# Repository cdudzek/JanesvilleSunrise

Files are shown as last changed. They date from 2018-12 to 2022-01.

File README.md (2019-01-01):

# JanesvilleSunrise
Arduino-based Sunrise Clock

## Introduction
This project is an Arduino-based clock that gradually increases the brightness on LED string lights at a preset time to emulate a sunrise, to gently wake you instead of a blaring alarm. Long Wisconsin winters are not known to have a bright sunrise every day, nor at the right time. 

## Electronics
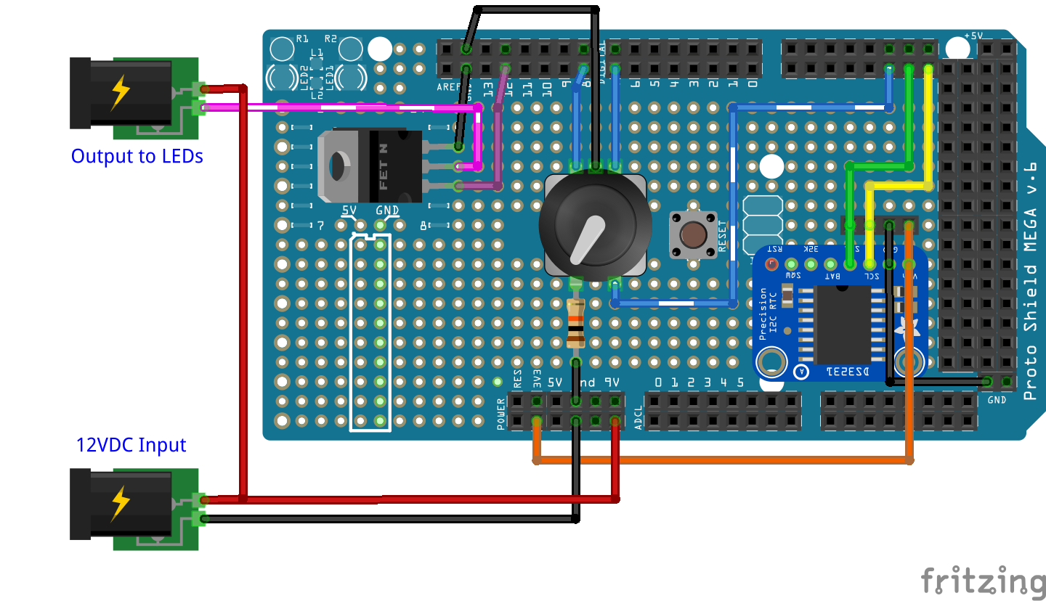
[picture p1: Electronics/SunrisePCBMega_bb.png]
Fritzing diagram
The Fritzing diagram of the electronics on the prototyping shield: 

An [Arduino Mega 2560](https://store.arduino.cc/usa/arduino-mega-2560-rev3) was used since I had one lying around, but any 5V-compatible Arduino board should work. I used a [Mega prototype shield](https://store.arduino.cc/usa/arduino-mega-proto-shield-rev3-pcb) to build the components.

A 12VDC power supply is used to power the Arduino and the LED string lights. A MOSFET is used to adjust the power to the LEDs up to 12V from a PWM pin on the Arduino board, without drawing the power through the Arduino itself. I used an [IRF530 MOSFET](https://www.vishay.com/docs/91019/91019.pdf) that I had available to power the LEDs. I had a [bright white LED tape light](https://www.amazon.com/gp/product/B00MHLIFO8/ref=oh_aui_detailpage_o05_s00?ie=UTF8&psc=1) which runs on 12VDC and included a power supply. To use RGB lights, three MOSFETs can be used to power the three LED channels separately, each driven from a separate PWM pin. 

An [Adafruit #3013 DS3231 Real Time Clock (RTC)](https://www.adafruit.com/product/3013) breakout board is used to keep accurate time, and the built-in battery backup to continue when power is lost. 

A single [Adafruit #377 Rotary Encoder](https://www.adafruit.com/product/377) is used to provide control to the user for setting the alarm time and device settings. Double-click the built-in button to enter the Setup Mode, which provides access to setting the current time, alarm time, display brightness, and maximum LED output brightness. Hold the button for a short while to start a sunrise fade-in right away. When a sunrise is happening (the LED lights are on), single-click the rotary button to cancel (or re-enable) the current sunrise cycle. 

A header is included next to the RTC to connect an [Adafruit I2C 7-Segment LED backpack](https://www.adafruit.com/product/881) as the clock display. I used the Adafruit #881 blue display, but other colors are available. The Arduino sketch and wiring could be modified to use an SPI or serial display such as the [Sparkfun #COM-11441](https://www.sparkfun.com/products/11441) display, or a [16x2 character LCD](https://www.adafruit.com/category/96), or other products. 

## Hardware and Enclosure
A simple wooden jewelry box from Hobby Lobby was used to enclose the electronics and to mount the display, encoder knob, and power jacks. 

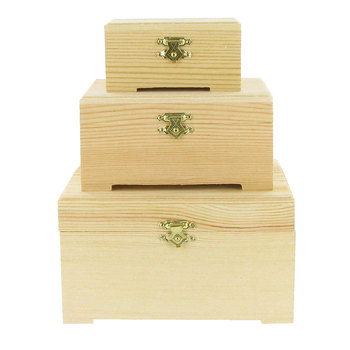
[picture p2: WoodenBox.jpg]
Wooden Box Housing, copyright Hobby Lobby


Holes were cut in the top lid for the LED display (with a simple utility knife) and the rotary knob (drill bit). Holes were drilled in the rear for the incoming 12VDC power and the output power for the LED strand. Panel mount DC barrel jacks such as the [Adafruit #610](https://www.adafruit.com/product/610) work well for mounting connectors on the wooden housing, and were the same size as the DC power supply for my LED strands. 

## Arduino Sketch
The [Arduino Sketch](https://github.com/cdudzek/JanesvilleSunrise/blob/master/MySunrise/MySunrise.ino) handles all RTC clock functions, LED clock display, user controls, and fading the LED strand lights in and out. 

The programmed alarm time is when the peak brightness for the LEDs will be on. The TIME_TO_FADE declaration in the sketch defines how long it will take to increase from darkness to full brightness. It is 20 minutes for my preferences but can be changed in the code. After the peak brightness at the exact alarm time, the lights will fade back out in an equal amount of time.

Note that the perceived brightness of the lights is not linear, see [this thread on Stack Exchange](https://electronics.stackexchange.com/questions/1983/correcting-for-non-linear-brightness-in-leds-when-using-pwm) for discussions about non-linear brightness. I implemented a simple exponential formula in the GetUserFade() function to calculate the brightness rather than hard-coding a lookup table with preset values: `fade = fmap * (fmap - 1) / 1000;`

The Arduino EEPROM is used to store user settings any time they are changed. This allows the display brightness, LED output brightness, and alarm time to be saved in case of a power failure. The RTC's own battery keeps the clock running accurately during a power outage. 

## Code Customization
Lights:
- Change `ledPin` to match the pin for your LED output voltage. Must be a PWM-capable pin on Arduinos.
- If using RGB lights, use 3 separate pins, one for each color.

Encoder:
- Change `encLow` and `encHigh` to the pins attached to your rotary encoder. They do not need to be interrupt-capable pins. 
- Change `encBtn` to one pin attached to the rotary encoder's button. This does not need to be an interrupt-capable pin. 
- Attach the rotary common/center pin to ground.
- Connect the other rotary button pin with a 10K resistor to ground (like a standard input button).
- To change the direction of the dial (CW / CCW) just reverse the encLow and encHigh values or swap the wires on the encoder itself.

Other:
- Change the address of your 7-Seg LED at `SEVENSEG_ADDR` if necessary.
- Change the `TIME_TO_FADE` to the number of seconds for the lights to fade in from completely off to completely on. Ex. 20 minutes = 20*60
- Note the Alarm Time setting is for peak brightness, not the beginning of the fade-in. Lights will fade-out for the same duration after the peak alarm time.
- Change the `AlarmOnDays` array to turn the sunrise alarm on or off for each day of the week (Sunday through Saturday). 

# NOTES
1. See the Arduino sketch for a list of required software libraries. 
1. I first attempted to use a [Teensy 3.2](https://www.pjrc.com/store/teensy32.html) microcontroller board due to its small size and great specs. However, the 3.3V board could not adequately power the LED strip lights to the full 12V. I changed over to the Arduino Mega which runs at 5V and was able to power the LEDs fully. 
1. It is possible the [Teensy 3.5](https://www.pjrc.com/store/teensy35.html) would have enough power on a 5V-tolerant board, but I have not tested it. Other Arduino boards such as the 5V-tolerant [Arduino Nano](https://store.arduino.cc/usa/arduino-nano) may also work for this project in small package. 

## Sketch Compilation
- The sketch could be successfully compiled for the Arduino Mega, Nano, Uno, and Teensy 3.5 with no code changes, with the proper supporting libraries installed. Each board would have extra available storage and memory space to add further features to the sketch.
- When compiled for an **Arduino Mega**, 8% of storage space and 14% of dynamic memory were used. 
- When compiled for an **Arduino Uno**, 63% of storage space and 58% of dynamic memory were used. 
- When compiled for an **Arduino Nano**, 67% of storage space and 58% of dynamic memory were used. 
- When compiled for a **Teensy 3.5**, 6% of storage space and 2% of dynamic memory were used. 

# License
This project is licensed under the Apache 2.0 License - see the [LICENSE](LICENSE) file for details.

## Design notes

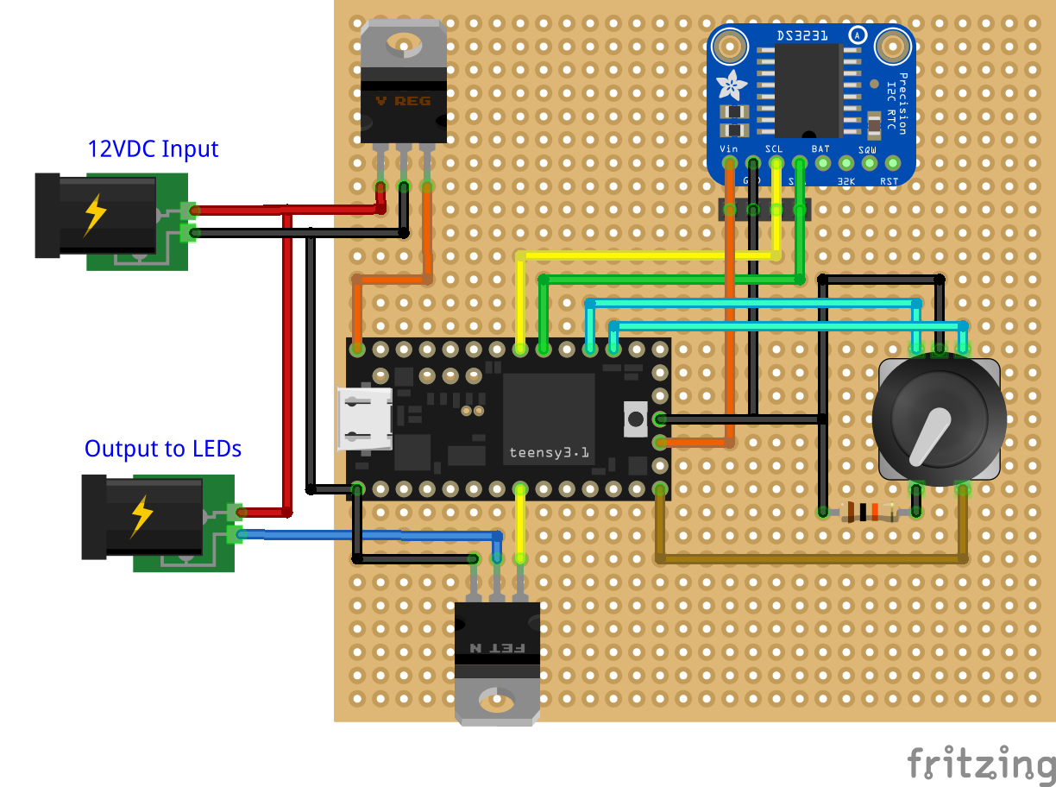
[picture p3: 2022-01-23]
Electronics/SunrisePCB-Teensy_bb.png

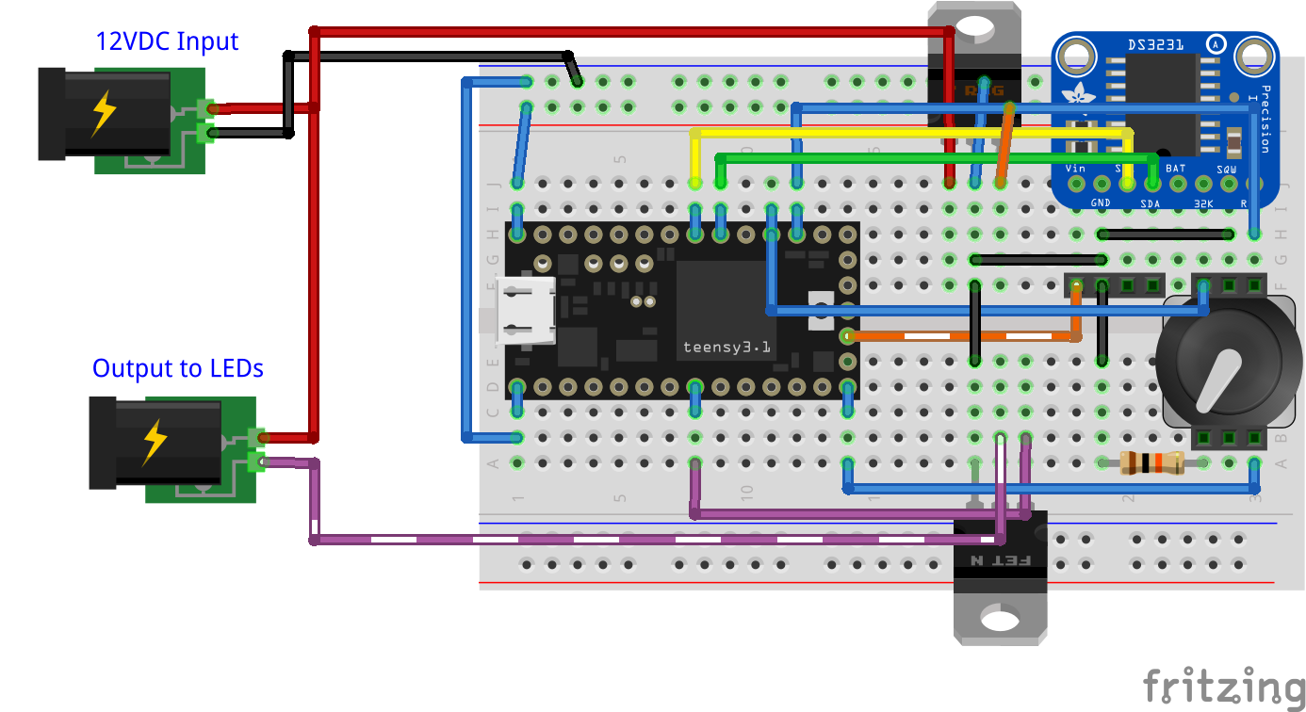
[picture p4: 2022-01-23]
Electronics/Teensy-MiniBB_bb.png

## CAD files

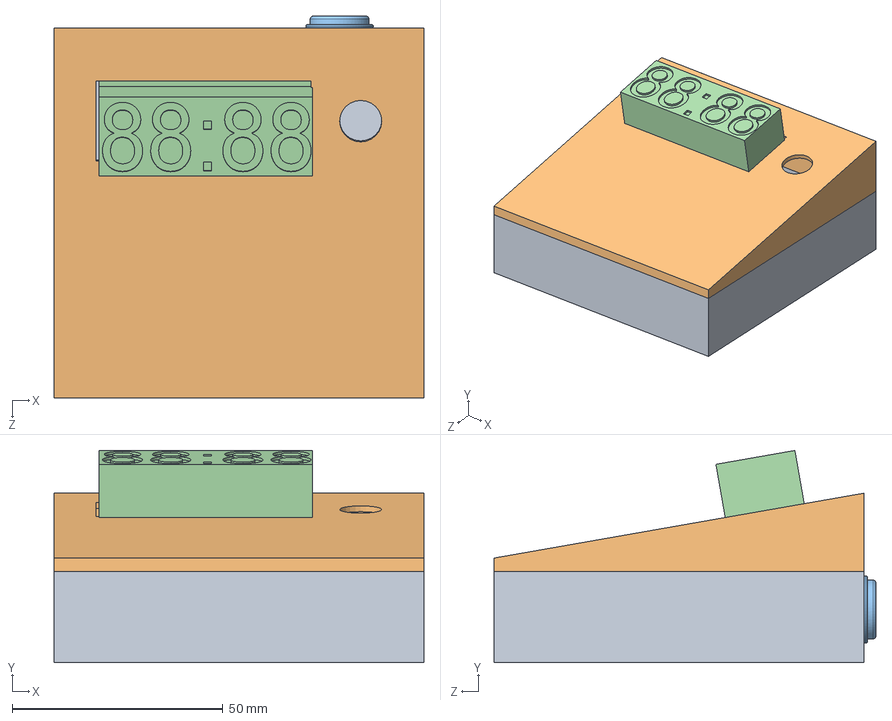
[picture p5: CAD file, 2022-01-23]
Solidworks/Assem1.SLDASM
87.8 x 50.4 x 90.7 mm
BaseBox
BoxLidSlanted
Barrel Jack
Clock

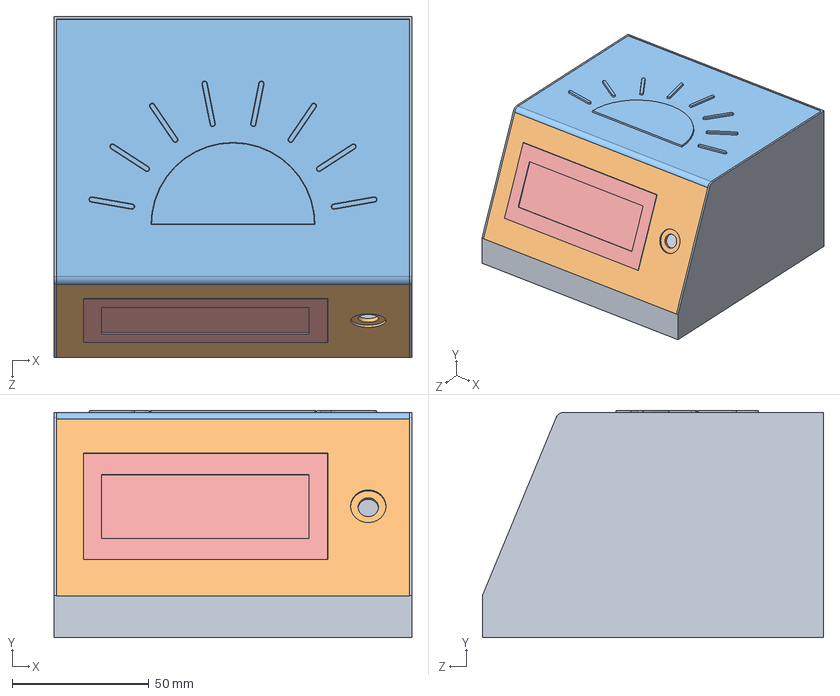
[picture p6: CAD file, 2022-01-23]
Solidworks/Box2.SLDASM
131.0 x 83.2 x 125.0 mm
Box2-Base
Box2-Front
Box2-Lid
Box2-LCDSpacer
LCD20x4

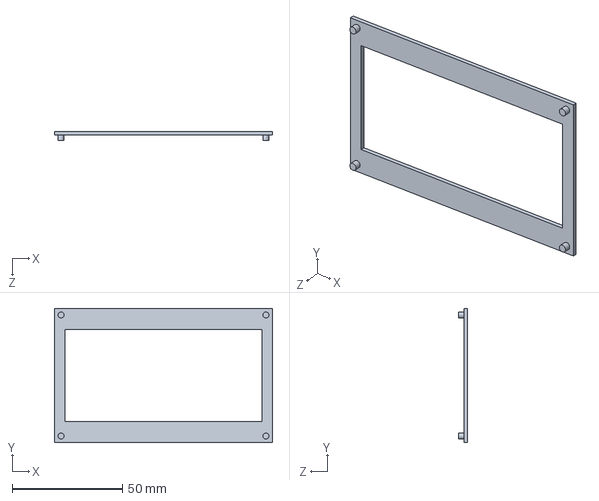
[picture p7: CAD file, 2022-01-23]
Solidworks/Box2-LCDSpacer.SLDPRT
99.0 x 61.0 x 4.00 mm

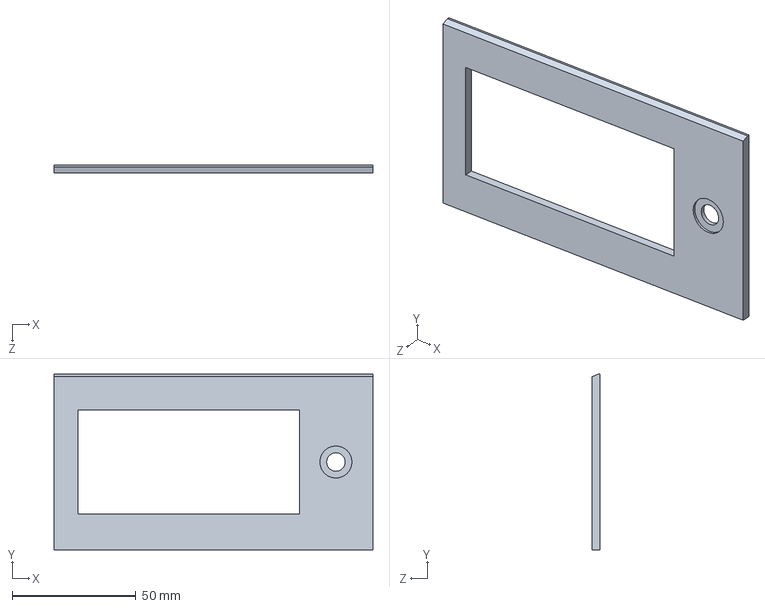
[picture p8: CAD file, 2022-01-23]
Solidworks/Box2-Front.SLDPRT
129.0 x 71.0 x 3.20 mm

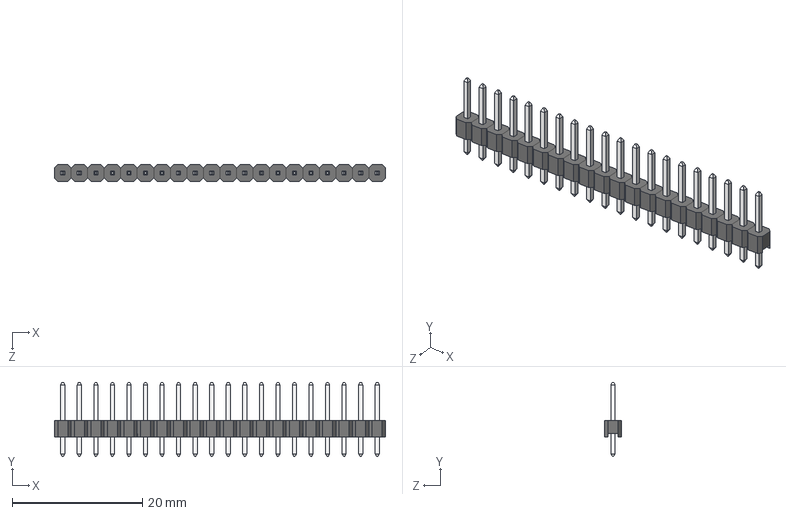
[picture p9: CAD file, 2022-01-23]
Solidworks/PREC020SAAN-RC.STEP
50.8 x 11.4 x 2.54 mm
1 row end bumps format x 20

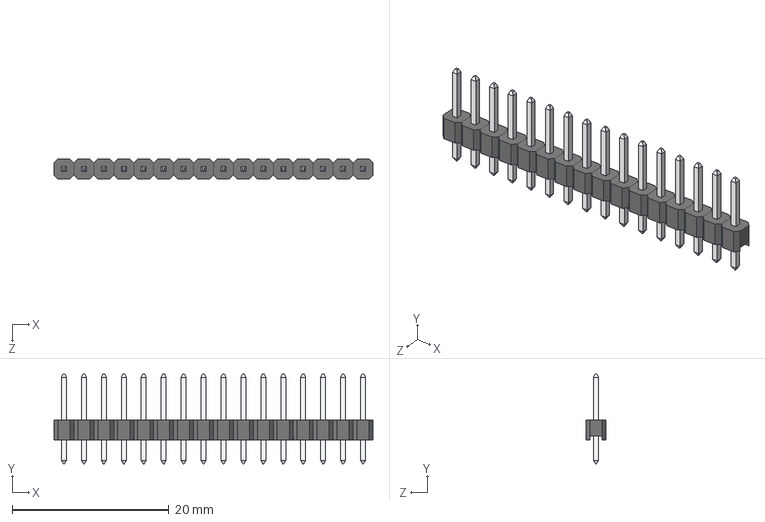
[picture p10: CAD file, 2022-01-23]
Solidworks/PREC016SAAN-RC.STEP
40.6 x 11.4 x 2.54 mm
1 row end bumps format x 16

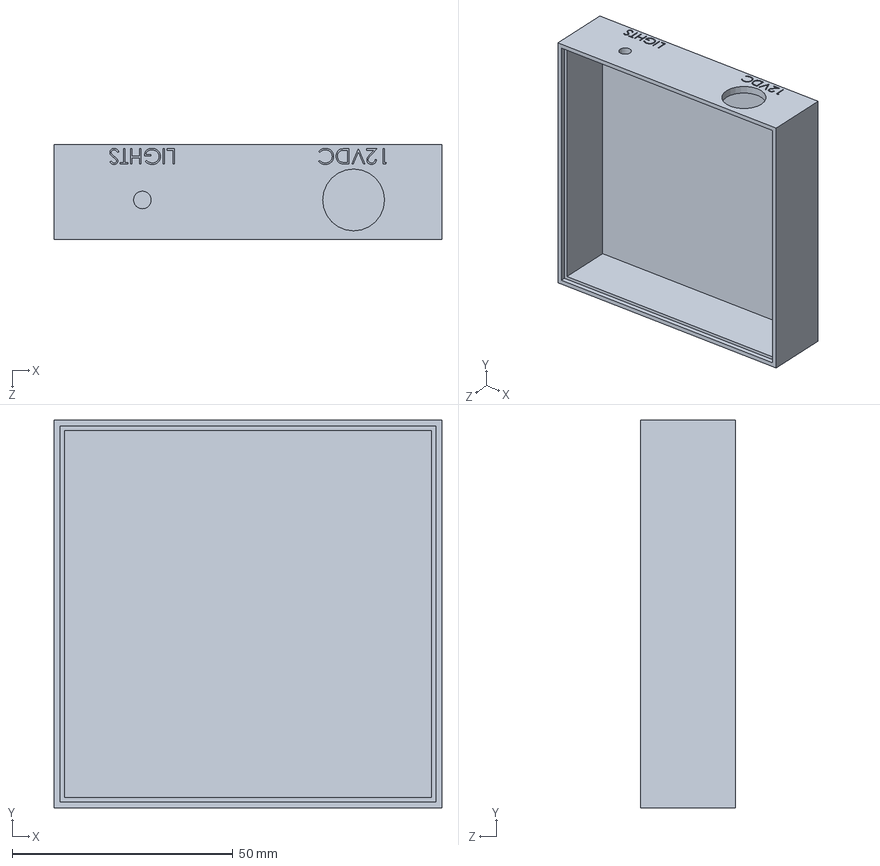
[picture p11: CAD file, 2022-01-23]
Solidworks/BaseBox.SLDPRT
87.8 x 87.8 x 21.6 mm

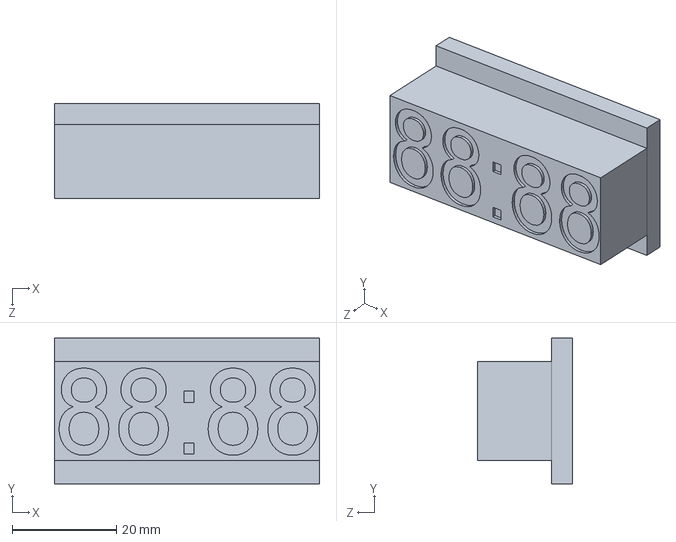
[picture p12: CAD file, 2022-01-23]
Solidworks/Clock.SLDPRT
50.8 x 27.9 x 18.3 mm

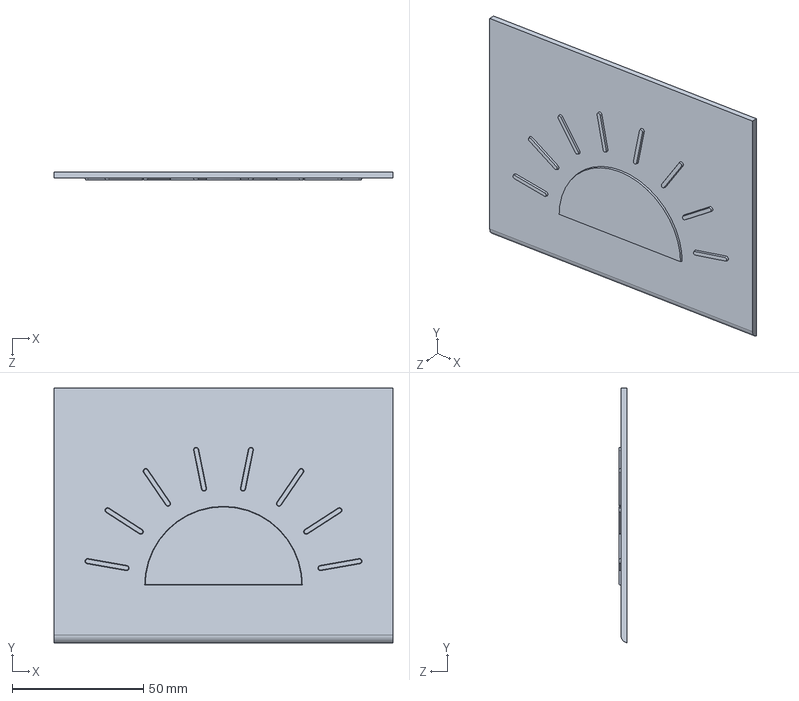
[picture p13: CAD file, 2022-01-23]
Solidworks/Box2-Lid.SLDPRT
129.0 x 97.0 x 3.20 mm

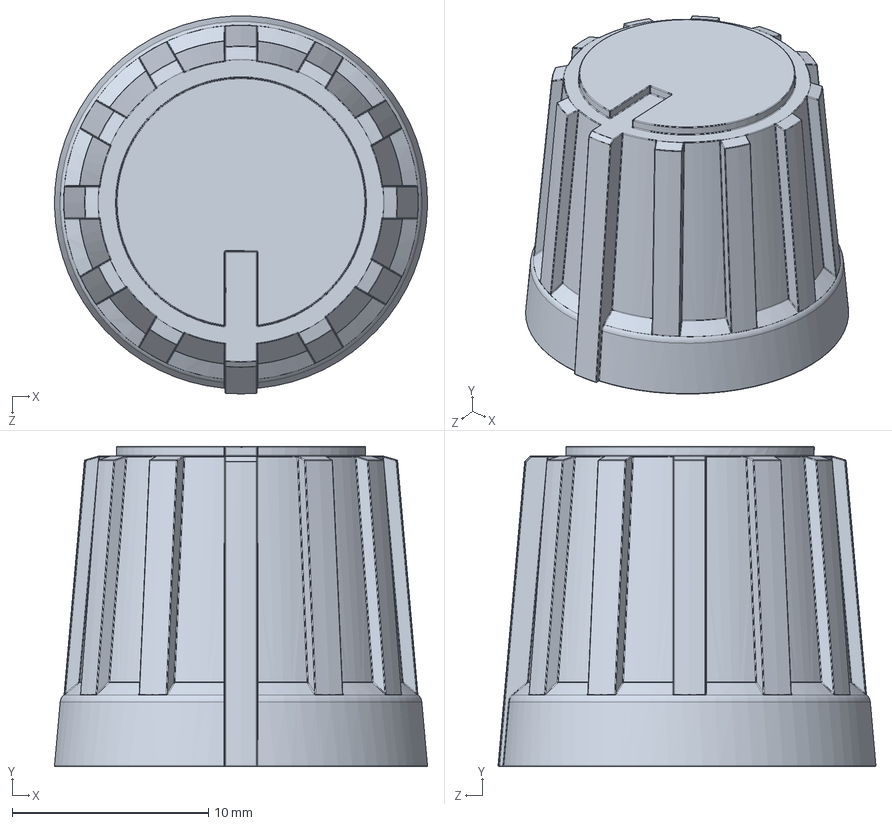
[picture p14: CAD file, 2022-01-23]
Solidworks/Turn knob.SLDPRT
19.0 x 16.3 x 19.2 mm

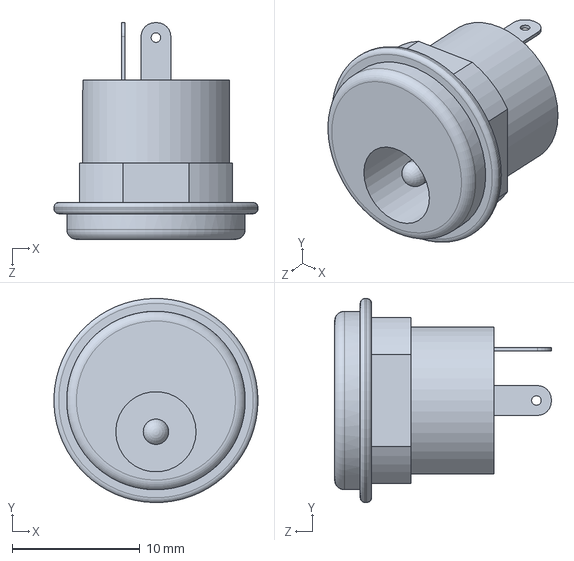
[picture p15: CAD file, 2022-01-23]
Solidworks/Barrel Jack.SLDPRT
16.0 x 16.0 x 17.0 mm

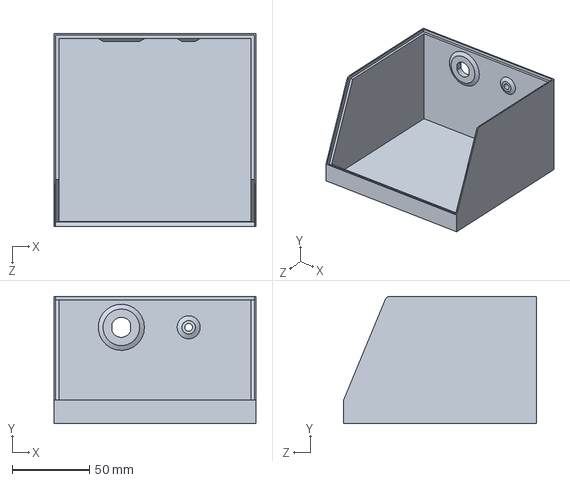
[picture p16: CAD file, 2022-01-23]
Solidworks/Box2-Base.SLDPRT
131.0 x 82.4 x 124.9 mm

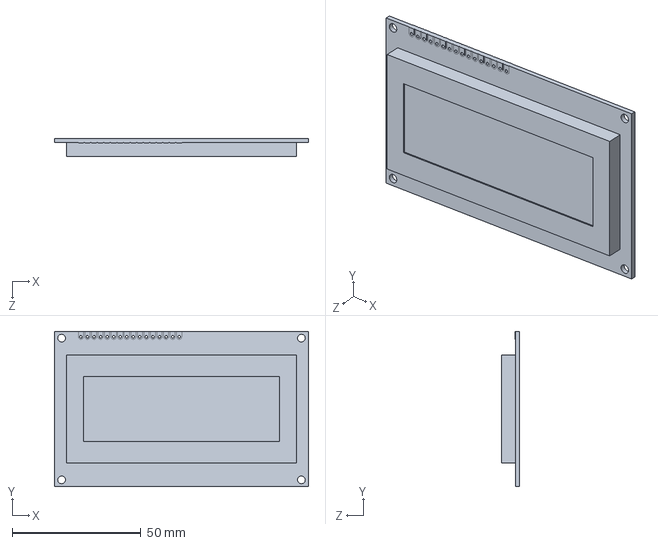
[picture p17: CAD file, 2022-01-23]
Solidworks/LCD20x4.SLDPRT
98.5 x 60.3 x 7.10 mm

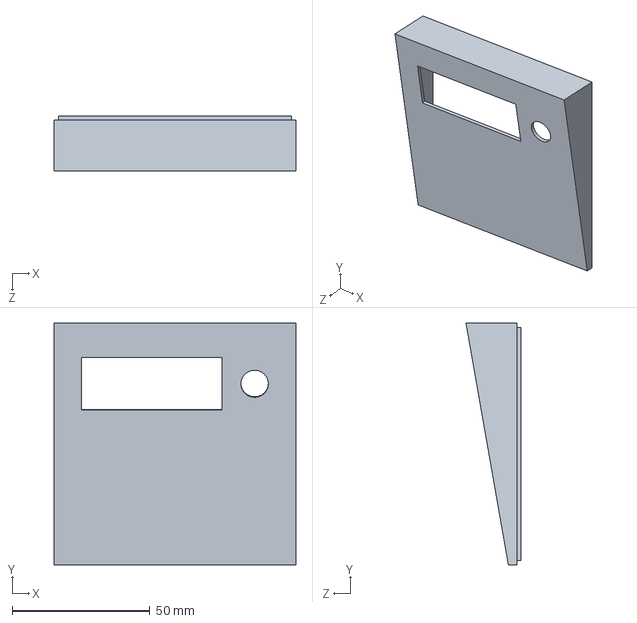
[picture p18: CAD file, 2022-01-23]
Solidworks/BoxLidSlanted.SLDPRT
87.8 x 87.8 x 20.0 mm

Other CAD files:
Solidworks/BoxLid.SLDPRT
Solidworks/Box2-Base.STL
Solidworks/Box2-Front.STL
Solidworks/Box2-LCDSpacer.STL
Solidworks/Box2-Lid.STL

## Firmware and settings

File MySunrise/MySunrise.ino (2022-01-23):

/*
 * "Janesville Sunrise"
 * December 2018 - Mr. D.
 * https://github.com/cdudzek/JanesvilleSunrise
 * 
 * Free to use, no warranty. If it breaks, not my problem.
 * See LICENSE document for Apache License 2.0
 */

/* CUSTOM BUILD TASKS:
 *   
 *  The default alarm clock is set with TimeSpan AlarmTime(...). Alarm settings will be saved to the Arduino EEPROM once changed.
 *  
 *  Change ledPin to match the pin for your LED output voltage. Must be a PWM-capable pin on Arduinos.
 *  
 *  Change encLow and encHigh to the pins attached to your rotary encoder. They do not need to be interrupt-capable pins. 
 *  Change encBtn to one pin attached to the rotary encoder's button. This does not need to be an interrupt-capable pin. 
 *  Attach the rotary common/center pin to ground.
 *  Connect the other rotary button pin with a 10K resistor to ground (like a standard input button).
 *  To change the direction of the dial (CW / CCW) just reverse the encLow and encHigh values or swap the wires on the encoder itself.
 *  
 *  Change the address of your 7-Seg LED at SEVENSEG_ADDR if necessary.
 *  
 *  Change the TIME_TO_FADE to the number of seconds for the lights to fade in from completely off to completely on. Ex. 20 minutes = 20*60
 *  Note the Alarm Time setting is for peak brightness, not the beginning of the fade-in. Lights will fade-out for the same duration after the peak alarm time.
 *  
 *  Change the AlarmOnDays array to turn the sunrise alarm on or off for each day of the week (Sunday through Saturday).
 */

/* Build information and libraries:
 *
 *  Required libraries: 
 *  Adafruit LED Backpack library: https://github.com/adafruit/Adafruit_LED_Backpack
 *  Adafruit GFX library: https://github.com/adafruit/Adafruit-GFX-Library
 *  ClickEncoder library: https://github.com/0xPIT/encoder/tree/arduino
 *  TimerOne library: http://playground.arduino.cc/Code/Timer1
 *  
 *  Products in use:
 *  Adafruit Blue 7-Segment LED with I2C backpack: https://www.adafruit.com/product/881
 *  Rotary Encoder (control knob): https://www.adafruit.com/product/377
 *  DS3231 RTC (Real-Time Clock): https://www.adafruit.com/product/3013
 *  Arduino Mega Protoshield (for circuitry): https://www.adafruit.com/product/192
 *  Arduino Mega 2560: https://store.arduino.cc/usa/arduino-mega-2560-rev3
 *  N-Channel MOSFET to drive LED power: I used an IRF530, a compatible product would be: https://www.adafruit.com/product/355
 *  
 *  Panel jacks such as https://www.adafruit.com/product/610 can be used to mount input/output connectors on your enclosure.
 *  If you desire an external USB connection for debugging/updating, consider a panel-mounted cable 
 *  such as https://www.adafruit.com/product/907 or https://www.adafruit.com/product/3258, depending on your board's USB port.
 *  
 *  Tested on Arduino Mega 2560, should work with Arduino Uno.
 *  Discovered the Teensy 3.2 does not have enough oomph to drive my 12V LED strands, may work with lower power output. 
 *  
 *  Circuitry built on Mega Protoshield, but any breadboard/protoboard could be used or a custom PCB could be made for this. 
 *  
 *  The DS3231 RTC will keep time accurately, and will maintain it during power loss if the battery is installed. Cell battery may last over 5 years.
 *  
 *  I built the clock into a wooden jewelry box enclosure (from Hobby Lobby). Size 5-7/8" x 4-3/4" x 3-1/4" was able to fit Arduino Mega.
 *  Holes were cut in the top lid for the clock display and rotary encoder/button, and in the rear for the input power and LED output connectors. 
 */

#include <Adafruit_GFX.h>
#include <Adafruit_LEDBackpack.h>
#include <ClickEncoder.h>
#include <EEPROM.h>
#include <LiquidCrystal.h>
#include <RTClib.h>
#include <TimerOne.h>

// TODO: Quick settings for Teensy or Mega pinouts
#define USING_TEENSY_SETTINGS
//#define USING_MEGA_SETTINGS

// TODO: Update pins for LED output and encoder/button if necessary
#ifdef USING_MEGA_SETTINGS
#define ledPin    8
#define encLow    2
#define encHigh   3
#define encBtn    19
// LCD character display pins (14-pin or 16-pin header)
// 1=GND, 2=+5v, 3=Pot/Contrast, 4=RS, 5=RW/GND, 6=EN, 7-10=empty, 11-14=DS4-DS7, 15=+Backlight, 16=-Backlight
#define LCD_RS    9
#define LCD_EN    10
#define LCD_D4    4
#define LCD_D5    5
#define LCD_D6    6
#define LCD_D7    7
bool USE_LCD = true;
bool USE_SEVENSEG = false;

#elif defined USING_TEENSY_SETTINGS
#define ledPin    9
#define encLow    15
#define encHigh   16
#define encBtn    12
// LCD character display pins (14-pin or 16-pin header)
// 1=GND, 2=+5v, 3=Pot/Contrast, 4=RS, 5=RW/GND, 6=EN, 7-10=empty, 11-14=DS4-DS7, 15=+Backlight, 16=-Backlight
#define LCD_RS    9
#define LCD_EN    10
#define LCD_D4    4
#define LCD_D5    5
#define LCD_D6    6
#define LCD_D7    7
bool USE_LCD = false;
bool USE_SEVENSEG = true;
#endif

// TODO: Update the I2C address for the 7-Segment LED backpack if necessary
#define SEVENSEG_ADDR  0x70

// TODO: Update for 16x2 or 20x4 LCD display
#define LCD_ROWS 4
#define LCD_COLS 20
LiquidCrystal lcd(LCD_RS, LCD_EN, LCD_D4, LCD_D5, LCD_D6, LCD_D7);

// TODO: Amount of time (in seconds) to fade in the lighting
// 20 minutes:
#define TIME_TO_FADE (10*60) 

// TODO: Adjust Max LED PWM brightness based on your controller
// Arduino 8-bit = 255
// Teensy 10-bit = 1023, 12-bit = 4095
#define LED_MAX_PWM_OUTPUT 255
#define ANALOG_RESOLUTION_BITS 8

// TODO: Turn the alarm on/off for each day of the week
bool AlarmOnDays[] = { false, true, true, true, true, false, false };   // array={Su,M,Tu,W,Th,F,Sa}
const String DaysOfTheWeek[] = {"Sunday", "Monday", "Tuesday", "Wednesday", "Thursday", "Friday", "Saturday"};    // For serial debugging output

#define CONST_DEAD 0xDEAD
#define CONST_BEEF 0xBEEF
#define CONST_SETTINGS_VERSION 1
struct ClockSettings {
  unsigned int dead = CONST_DEAD;    // To test if settings are read correctly from EEPROM
  int SettingsVersion;
  int LCDBrightness;    // 0-15
  int MaxLEDBrightness; // 0 - LED_MAX_PWM_OUTPUT
  bool Use24HR;
  bool AlarmDays[7];
  int Alarm1Hours;
  int Alarm1Minutes;
  int Alarm2Hours;        // Alarm2 not currently in use
  int Alarm2Minutes;
  bool Alarm1Enabled;
  bool Alarm2Enabled;
  unsigned int beef = CONST_BEEF;    // To test if settings are read correctly from EEPROM
};

ClockSettings CurrentSettings;      // Where current settings are stored in memory
Adafruit_7segment matrix = Adafruit_7segment();
RTC_DS3231 rtc;
ClickEncoder *encoder;
ClickEncoder::Button encoderButton;
long oldPosition  = 0;    // For encoder position
long newPosition  = 0;    // For encoder position
bool UserSunrise;     // Temporary (user-started) sunrise
bool Cancelled;   // Allow the light to be turned off
DateTime UserDateTime;
DateTime CurrentTime;
DateTime AlarmDateTime;
TimeSpan AlarmTime(0, 6, 40, 0);    // Default alarm time = (0, Hour, Minute, Second); Can be set using the rotary dial
int hours, minutes, seconds;
long millisec;

/*
 * Displaying characters on 7-segment (non-alpha)
 * values for the segments are :
  1 = top
  2 = upper right
  4 = lower right
  8 = bottom
  16 = lower left
  32 = upper left
  64 = middle
 */
#define CHAR7_A 0x77
#define CHAR7_b 0x7c
#define CHAR7_C 0x39
#define CHAR7_c 0x58
#define CHAR7_d 0x5e
#define CHAR7_E 0x79
#define CHAR7_h 0x74
#define CHAR7_H 0x76
#define CHAR7_L 0x38
#define CHAR7_l 0x30
#define CHAR7_n 0x54
#define CHAR7_O 0x3F
#define CHAR7_o 0x5c
#define CHAR7_P 0x73
#define CHAR7_r 0x50
#define CHAR7_t 0x78
#define CHAR7_u 0x1c

void setup() {
  Serial.begin(9600);

  // Default Settings
  CurrentSettings.LCDBrightness = 15;
  CurrentSettings.MaxLEDBrightness = LED_MAX_PWM_OUTPUT;
  CurrentSettings.Use24HR = false;
  CurrentSettings.Alarm1Hours = AlarmTime.hours();
  CurrentSettings.Alarm1Minutes = AlarmTime.minutes();
  CurrentSettings.Alarm2Hours = AlarmTime.hours();
  CurrentSettings.Alarm2Minutes = AlarmTime.minutes();
  CurrentSettings.Alarm1Enabled = true;
  CurrentSettings.Alarm2Enabled = false;
  ReadEEprom();
  CurrentSettings.dead = CONST_DEAD;
  CurrentSettings.beef = CONST_BEEF;
  CurrentSettings.SettingsVersion = CONST_SETTINGS_VERSION;

  if (! rtc.begin()) {    
    while (1) {
      Serial.println("Couldn't find RTC");
    }
  }

  if (rtc.lostPower()) {
    Serial.println("RTC lost power, lets set the time!");
    // following line sets the RTC to the date & time this sketch was compiled
    rtc.adjust(DateTime(F(__DATE__), F(__TIME__)));
    // This line sets the RTC with an explicit date & time, for example to set
    // January 21, 2014 at 3am you would call:
    // rtc.adjust(DateTime(2014, 1, 21, 3, 0, 0));
  }

  hours = minutes = seconds = 0; 
  Cancelled = false;
  UserSunrise = false;
  UserDateTime = rtc.now(); // Initialize variable, though we are not using it yet

  // Clear the displays
  if (USE_SEVENSEG)
  {
    matrix.begin(SEVENSEG_ADDR);
    matrix.setBrightness(CurrentSettings.LCDBrightness % 16);    // 0-15
  }
  if (USE_LCD)
    lcd.begin(LCD_COLS, LCD_ROWS);

#ifdef USING_TEENSY_SETTINGS
  analogWriteResolution(ANALOG_RESOLUTION_BITS);
#endif
  
  pinMode(ledPin, OUTPUT);
  encoder = new ClickEncoder(encLow, encHigh, encBtn, 4, LOW);    // Adafruit #377 encoder = 4 steps/notch
  encoder->setAccelerationEnabled(false);
  Timer1.initialize(1000);
  Timer1.attachInterrupt(timerIsr);   // Timer1 to service encoder
}

void loop() {
  GetCurrentTime();
  if ((CurrentTime.hour() != hours) || (CurrentTime.minute() != minutes) || (CurrentTime.second() != seconds)) {
    hours = CurrentTime.hour();
    minutes = CurrentTime.minute();
    seconds = CurrentTime.second();
    UpdateDisplay();
  }

  // See if user wants to do anything
  CheckButtonState();

  // Adjust the lights
  int fade = max(GetAlarmFade(), GetUserFade());
  analogWrite(ledPin, map(fade, 0, LED_MAX_PWM_OUTPUT, 0, CurrentSettings.MaxLEDBrightness));
}

// timerIsr(): called once per ms by Timer1 to handle rotary encoder without using interrupt pins
void timerIsr() {
  encoder->service();
}

// FormatHMS(): return HH or MM string with or without zeroes for proper formatting
String FormatHMS(int val, bool addzero = true) {
  if (addzero && (val < 10))
    return ("0" + String(val));
  else if (val < 10)
    return (" " + String(val));
  else
    return String(val);
}

String CenterString(String str, int columns = LCD_COLS) {  
  int diff = (columns - str.length())/2;
  for (int sp = 0; sp < diff; sp++)
    str = " " + str;
  for (int sp = str.length(); sp < columns; sp++)
    str += " ";   
  return str.substring(0, 20);
}

// UpdateDisplay(): Update the 7-segment clock display
void UpdateDisplay() {
  int hr = hours;
  String ampm = "";

  if (!CurrentSettings.Use24HR)  
  {
    if (hr > 12)
    {
      hr -= 12;
      ampm = " PM";
    }
    else if (hr == 12)
      ampm = " PM";
    else 
      ampm = " AM";
  }
  
  if (USE_SEVENSEG)
  {
    matrix.print((hr*100) + minutes);
    matrix.drawColon(true);
    matrix.writeDisplay();
  }
  if (USE_LCD)
  {
    //lcd.clear();
    String str;
    lcd.setCursor(0, 0);
    str = String(hr) + ":" + FormatHMS(minutes) + ":" + FormatHMS(seconds) + ampm;
    lcd.print(CenterString(str, LCD_COLS));
    lcd.setCursor(0, 1);
    if (LCD_COLS == 20)
      str = DaysOfTheWeek[CurrentTime.dayOfTheWeek()];
    else
      str = DaysOfTheWeek[CurrentTime.dayOfTheWeek()].substring(0,3);
    str += " " + FormatHMS(CurrentTime.month()) + "/" + FormatHMS(CurrentTime.day()) + "/" + CurrentTime.year(); 
    lcd.print(CenterString(str, LCD_COLS));
    
    if (LCD_ROWS == 4)
    {
      lcd.setCursor(0, 2);
      ampm = "";
      hr = AlarmDateTime.hour();
      if (!CurrentSettings.Use24HR)  
      {
        if (hr > 12)
        {
          hr -= 12;
          ampm = " PM";
        }
        else 
          ampm = " AM";
      }
      int next = NextAlarmDayOfWeek();
      str = "Alarm ";
      if ((next < 0 || next >= 7) || !CurrentSettings.Alarm1Enabled)
      {
        str += "Off";
        lcd.print(CenterString(str, LCD_COLS));
        lcd.setCursor(0, 3);
        lcd.print(CenterString(" ", LCD_COLS));
      }
      else
      {
        str += String(hr) + ":" + FormatHMS(AlarmDateTime.minute()) + ampm;
        lcd.print(CenterString(str, LCD_COLS));

        lcd.setCursor(0, 3);
        if (next >= 0 && next < 7)
        {
          str = "Next: ";
          if (next == CurrentTime.dayOfTheWeek() && 
            (CurrentTime.hour() < AlarmDateTime.hour()) &&
            (CurrentTime.minute() < AlarmDateTime.minute()))
            str += "Today";
          else if (next == (CurrentTime.dayOfTheWeek()+1)%7)
            str += "Tomorrow";
          else 
            str += DaysOfTheWeek[next];
          lcd.print(CenterString(str, LCD_COLS));
        }
      }      
    }
  }
  
  Serial.println(DaysOfTheWeek[CurrentTime.dayOfTheWeek()] + " " + FormatHMS(hours) + ":" + FormatHMS(minutes) + ":" + FormatHMS(seconds) + " (" + String(millisec) + " ms) Fade=" + String(GetAlarmFade()));
}

int NextAlarmDayOfWeek() {
  bool enabled = false;
  // check if at least one day is enabled
  for (int d = 0; d < 7; d++)
    if (AlarmOnDays[d])
      enabled = true;
  if (!enabled) 
    return -1;
    
  int dow = CurrentTime.dayOfTheWeek();
  dow %= 7; // just in case
  
  do 
  {
    if (AlarmOnDays[dow])
    {
      if (dow == CurrentTime.dayOfTheWeek() && 
        (hours < AlarmDateTime.hour()) &&
        (minutes < AlarmDateTime.minute()))
        break;
      else if (dow != CurrentTime.dayOfTheWeek())
        break;
      else
        dow++;
    }
    else 
      dow++;  // increment
    dow %= 7; // loop around 7 days
  }
  while (dow != CurrentTime.dayOfTheWeek());

  //Serial.println("Next alarm day is " + DaysOfTheWeek[dow]);
  
  return dow;  
}

// ReadEEprom(): restore settings after power loss
void ReadEEprom() {
  ClockSettings tmpset;
  unsigned int offset = 0;
  unsigned int dead = 0;
  unsigned int beef = 0;
  String stmp; 
  EEPROM.get(offset, dead);
  stmp = String(dead, HEX);
  stmp.toUpperCase();
  Serial.println("Offset " + String(offset) + ": dead = 0x" + stmp);
  offset += sizeof(dead);
  EEPROM.get(offset, tmpset.SettingsVersion);
  Serial.println("Offset " + String(offset) + ": SettingsVersion = " + String(tmpset.SettingsVersion));
  offset += sizeof(ClockSettings::SettingsVersion);
  EEPROM.get(offset, tmpset.LCDBrightness);
  Serial.println("Offset " + String(offset) + ": LCDBrightness = " + String(tmpset.LCDBrightness));
  offset += sizeof(ClockSettings::LCDBrightness);
  EEPROM.get(offset, tmpset.MaxLEDBrightness);
  Serial.println("Offset " + String(offset) + ": MaxLEDBrightness = " + String(tmpset.MaxLEDBrightness));
  offset += sizeof(ClockSettings::MaxLEDBrightness);
  EEPROM.get(offset, tmpset.Use24HR);
  Serial.print("Offset " + String(offset));
  Serial.println(tmpset.Use24HR ? ": Use24HR" : ": Use12HR");
  offset += sizeof(ClockSettings::Use24HR);
  Serial.println("Offset " + String(offset) + ": AlarmDays[]");
  for (int d = 0; d < 7; d++) {
    EEPROM.get(offset, tmpset.AlarmDays[d]);
    offset += sizeof(bool);
  }
  EEPROM.get(offset, tmpset.Alarm1Hours);
  Serial.println("Offset " + String(offset) + ": Alarm1Hours = " + String(tmpset.Alarm1Hours));
  offset += sizeof(ClockSettings::Alarm1Hours);
  EEPROM.get(offset, tmpset.Alarm1Minutes);
  Serial.println("Offset " + String(offset) + ": Alarm1Minutes = " + String(tmpset.Alarm1Minutes));
  offset += sizeof(ClockSettings::Alarm1Minutes);
  EEPROM.get(offset, tmpset.Alarm2Hours);
  Serial.println("Offset " + String(offset) + ": Alarm2Hours = " + String(tmpset.Alarm2Hours));
  offset += sizeof(ClockSettings::Alarm2Hours);
  EEPROM.get(offset, tmpset.Alarm2Minutes);
  Serial.println("Offset " + String(offset) + ": Alarm2Minutes = " + String(tmpset.Alarm2Minutes));
  offset += sizeof(ClockSettings::Alarm2Minutes);
  EEPROM.get(offset, tmpset.Alarm1Enabled);
  Serial.print("Offset " + String(offset));
  Serial.println(tmpset.Alarm1Enabled ? ": Alarm 1 On" : ": Alarm 1 Off");
  offset += sizeof(ClockSettings::Alarm1Enabled);
  EEPROM.get(offset, tmpset.Alarm2Enabled);
  Serial.print("Offset " + String(offset));
  Serial.println(tmpset.Alarm2Enabled ? ": Alarm 2 On" : ": Alarm 2 Off");
  offset += sizeof(ClockSettings::Alarm2Enabled);
  EEPROM.get(offset, beef);
  stmp = String(beef, HEX);
  stmp.toUpperCase();
  Serial.println("Offset " + String(offset) + ": beef = 0x" + stmp);
  offset += sizeof(beef);
  Serial.println("Total length " + String(offset));  
  
  if (dead == 0xDEAD && beef == 0xBEEF) {
    CurrentSettings = tmpset;
    Serial.println("Successfully loaded settings from memory.");
  }
  else
    Serial.println("Could not load settings from memory.");
}

// WriteEEprom(): save settings to non-volatile memory in case of power loss
void WriteEEprom() {
  // From https://www.arduino.cc/en/Tutorial/EEPROMUpdate
  // "the EEPROM has also a limit of 100,000 write cycles per single location, therefore avoiding rewriting the same value in any location will increase the EEPROM overall life."
  ClockSettings tmpset;
  EEPROM.get(0, tmpset);
  bool putdays = false;  
  unsigned int offset = 0;
  String stmp;

  stmp = String(CurrentSettings.dead, HEX);
  stmp.toUpperCase();
  Serial.println("Offset " + String(offset) + ": dead = 0x" + stmp);
  if (tmpset.dead != CONST_DEAD)
    EEPROM.put(offset, CONST_DEAD);
  offset += sizeof(ClockSettings::dead);
  Serial.println("Offset " + String(offset) + ": SettingsVersion = " + String(CurrentSettings.SettingsVersion));
  if (tmpset.SettingsVersion != CurrentSettings.SettingsVersion)
    EEPROM.put(offset, CurrentSettings.SettingsVersion);
  offset += sizeof(ClockSettings::SettingsVersion);
  Serial.println("Offset " + String(offset) + ": LCDBrightness = " + String(CurrentSettings.LCDBrightness));
  if (tmpset.LCDBrightness != CurrentSettings.LCDBrightness)
    EEPROM.put(offset, CurrentSettings.LCDBrightness);
  offset += sizeof(ClockSettings::LCDBrightness);
  Serial.println("Offset " + String(offset) + ": MaxLEDBrightness = " + String(CurrentSettings.MaxLEDBrightness));
  if (tmpset.MaxLEDBrightness != CurrentSettings.MaxLEDBrightness)
    EEPROM.put(offset, CurrentSettings.MaxLEDBrightness);
  offset += sizeof(ClockSettings::MaxLEDBrightness);
  Serial.print("Offset " + String(offset));
  Serial.println(CurrentSettings.Use24HR ? ": Use24HR" : ": Use12HR");
  if (tmpset.Use24HR != CurrentSettings.Use24HR)
    EEPROM.put(offset, CurrentSettings.Use24HR);
  offset += sizeof(ClockSettings::Use24HR);
  Serial.println("Offset " + String(offset) + ": AlarmDays[]");
  for (int d = 0; d < 7; d++) {
    if (tmpset.AlarmDays[d] != CurrentSettings.AlarmDays[d])
      putdays = true;
  }
  if (putdays) {
    for (int d = 0; d < 7; d++) {
      EEPROM.put(offset, CurrentSettings.AlarmDays[d]);
      offset += sizeof(bool);
    }
  }
  else 
    offset += sizeof(ClockSettings::AlarmDays);
  Serial.println("Offset " + String(offset) + ": Alarm1Hours = " + String(CurrentSettings.Alarm1Hours));
  if (tmpset.Alarm1Hours != CurrentSettings.Alarm1Hours)
    EEPROM.put(offset, CurrentSettings.Alarm1Hours);
  offset += sizeof(ClockSettings::Alarm1Hours);
  Serial.println("Offset " + String(offset) + ": Alarm1Minutes = " + String(CurrentSettings.Alarm1Minutes));
  if (tmpset.Alarm1Minutes != CurrentSettings.Alarm1Minutes)
    EEPROM.put(offset, CurrentSettings.Alarm1Minutes);
  offset += sizeof(ClockSettings::Alarm1Minutes);
  Serial.println("Offset " + String(offset) + ": Alarm2Hours = " + String(CurrentSettings.Alarm2Hours));
  if (tmpset.Alarm2Hours != CurrentSettings.Alarm2Hours)
    EEPROM.put(offset, CurrentSettings.Alarm2Hours);
  offset += sizeof(ClockSettings::Alarm2Hours);
  Serial.println("Offset " + String(offset) + ": Alarm2Minutes = " + String(CurrentSettings.Alarm2Minutes));
  if (tmpset.Alarm2Minutes != CurrentSettings.Alarm2Minutes)
    EEPROM.put(offset, CurrentSettings.Alarm2Minutes);
  offset += sizeof(ClockSettings::Alarm2Minutes);
  Serial.print("Offset " + String(offset));
  Serial.println(CurrentSettings.Alarm1Enabled ? ": Alarm 1 On" : ": Alarm 1 Off");
  if (tmpset.Alarm1Enabled != CurrentSettings.Alarm1Enabled)
    EEPROM.put(offset, CurrentSettings.Alarm1Enabled);
  offset += sizeof(ClockSettings::Alarm1Enabled);
  Serial.print("Offset " + String(offset));
  Serial.println(CurrentSettings.Alarm2Enabled ? ": Alarm 2 On" : ": Alarm 2 Off");
  if (tmpset.Alarm2Enabled != CurrentSettings.Alarm2Enabled)
    EEPROM.put(offset, CurrentSettings.Alarm2Enabled);
  offset += sizeof(ClockSettings::Alarm2Enabled);
  stmp = String(CurrentSettings.beef, HEX);
  stmp.toUpperCase();
  Serial.println("Offset " + String(offset) + ": beef = 0x" + stmp);
  if (tmpset.beef != CONST_BEEF)
    EEPROM.put(offset, CONST_BEEF);
  offset += sizeof(ClockSettings::beef);
  Serial.println("Total length " + String(offset));  
}
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

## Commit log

2018-12-27 Added Fritzing files for electronics design
    [SunrisePCBMega.fzz]
2018-12-27 Added Arduino sketch and supporting libraries
2022-01-23 Add 3D-printed housing with Solidworks model (replaces cheap wooden box).
    [Assem1.SLDASM, Barrel Jack.SLDPRT, BaseBox.SLDPRT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]
2022-01-23 Add Fritzing designs using Teensy board (unfinished design)
    [SunrisePCB-Teensy.fzz, Teensy-MiniBB.fzz]
2022-01-23 Update Arduino sketch to allow use of 20x4 LCD, allow switching configurable options for Arduino Mega and Teensy boards.
